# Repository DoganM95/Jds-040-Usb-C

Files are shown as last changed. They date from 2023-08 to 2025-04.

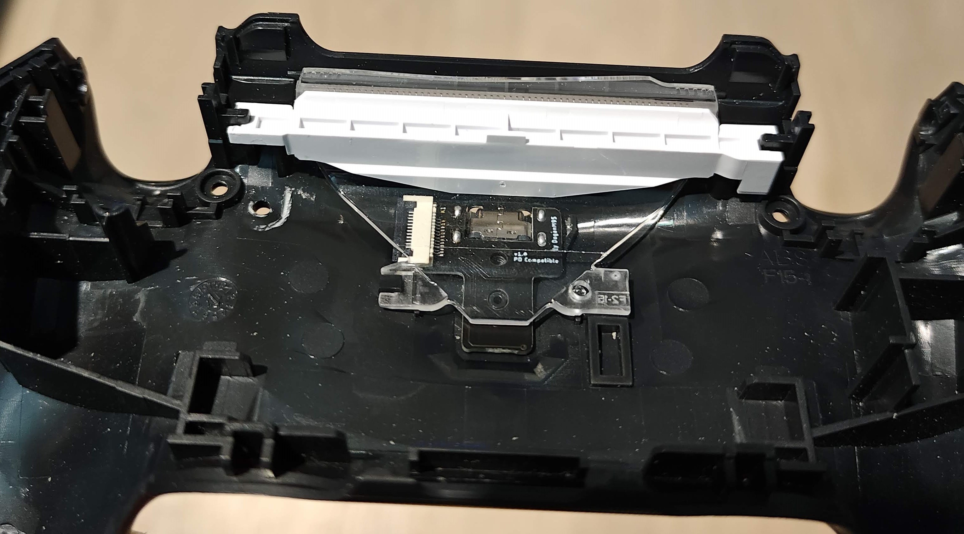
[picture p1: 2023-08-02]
assets/IMG_20230802_171910.jpg

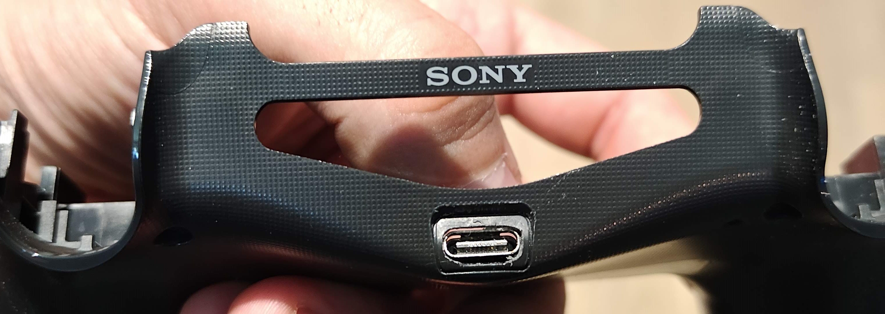
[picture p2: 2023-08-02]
assets/IMG_20230802_171401.jpg

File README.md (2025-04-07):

# DS4-UsbC-Mod

Custom pcb to replace Dualshock 4's micro b port with usb c (PD compatible). It was made to replace the jds-040 model but might be a compatible replacement for other models.

<table>
  <tr>
    <td>USB-C PCB Bottom View</td>
    <td>USB-C PCB Top View</td>
  </tr>
</table>

<table>
  <tr>
    <td>USB-C PCB Top View</td>
    <td>USB-C PCB Bottom View</td>
  </tr>
</table>

## FPC pinout

Starting with the pin that is closest to the charge port and ending with the pin that is closest to the led's:

1. GND
2. GND
3. D +
4. D -
5. GND
6. GND
7. Green LED (3V3_G)
8. Red LED VCC (2V2_G)
9. Blue LED VCC (3V_G)
10. LED VCC
11. USB 5V
12. USB 5V

## Key features
- Usb C port (with D+ and D-)
- Compatible with power delivery (communicates to get 5V)
- Compatible with any 5V usb port
- Uses easily accessible components (Aliexpress)
- Dual RGB led's

## Parts
- PCB: Get the latest gerber zip in releases and order it from Jlcpcb, with 1mm PCB thickness
- FPC connector (pins:12, pitch:0.5mm. Salvage it from an existing board -> ) https://a.aliexpress.com/_EjykXX1
- Led's (RGB, side view) https://a.aliexpress.com/_EHr7vQn
- Resistors (size:0603, res:5.1kOhm) https://a.aliexpress.com/_EIPYwrH
- USB C (female, pins:16, padding-bottom:0.8mm) https://a.aliexpress.com/_EJhQRSJ

## Tools (recommended next to the obvious)
- Hot plate
- Flux
- Solder wick
- Hot air gun

# Procedure
- Get the salvageable micro b module from aliexpress ready
- Use a hot air gun to desolder the usb micro b port
- Fire up the hot plate & put the pcb on it
- Steal the fpc connector from it
- Get the blank usb c pcb ready
- Solder the fpc connector to it (sides first in good position)
- Solder the usb c port's 4 shell pads in good position
- Solder usb c pins
- Solder solder smd resistors
- Solder smd led's
  - Put solder on the pcb pads
  - Put solder on the led's pads
  - Solder the middle 2 pins first
  - Solder the sides

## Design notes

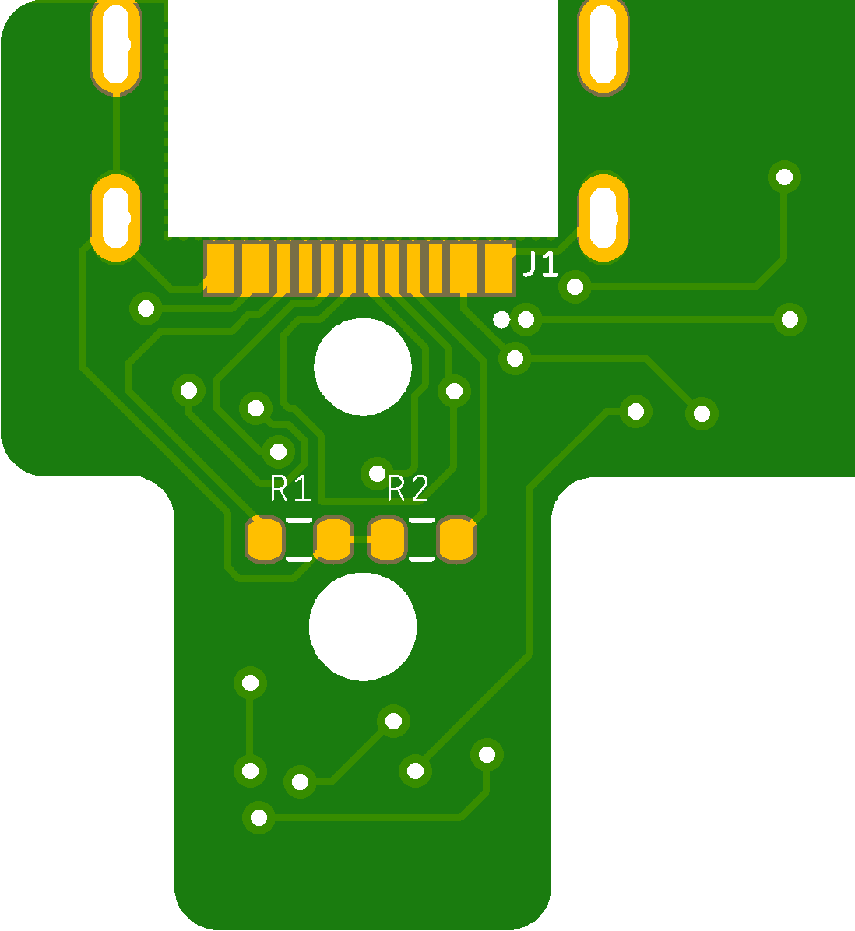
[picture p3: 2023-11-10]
assets/Jds-040-Usb-C_bottom.png

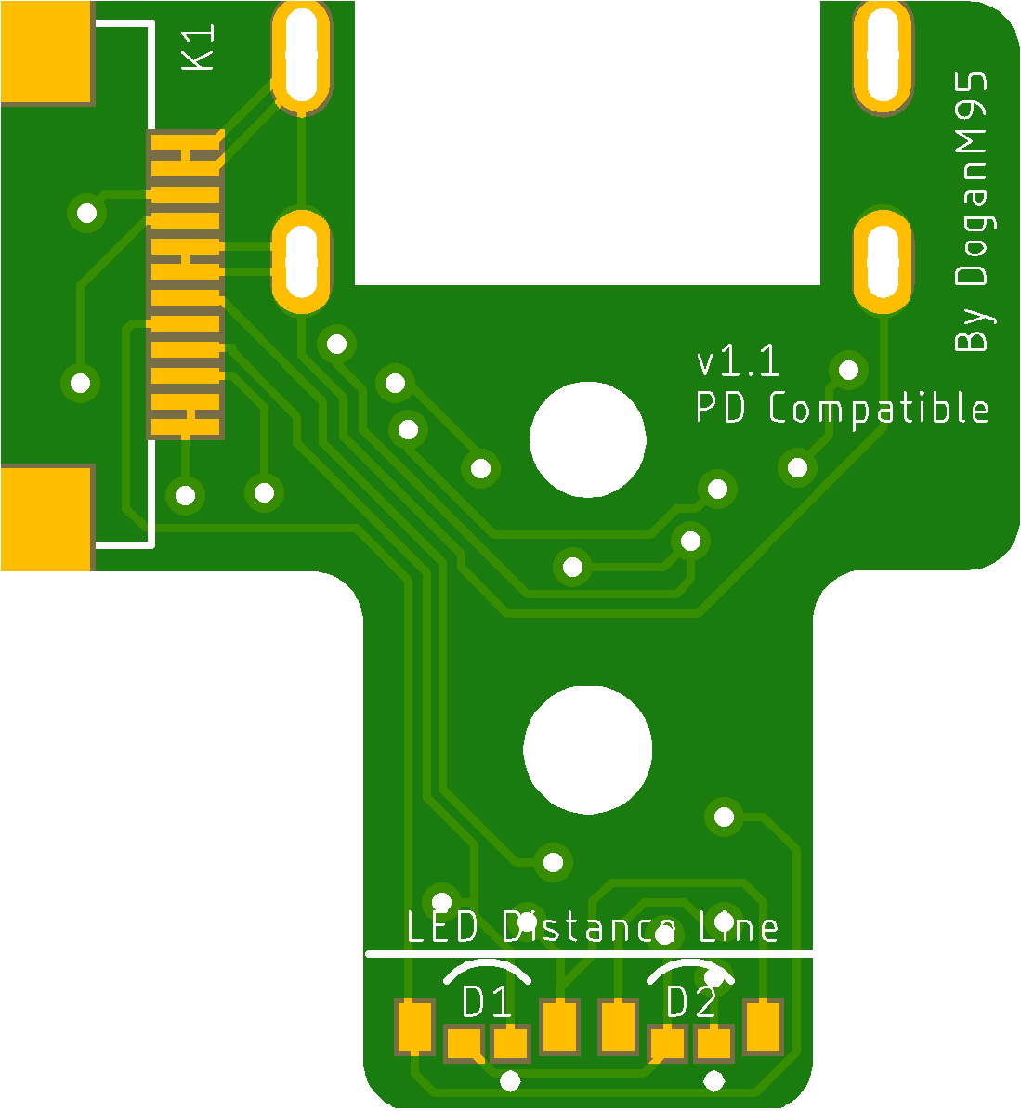
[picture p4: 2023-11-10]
assets/Jds-040-Usb-C_top.png

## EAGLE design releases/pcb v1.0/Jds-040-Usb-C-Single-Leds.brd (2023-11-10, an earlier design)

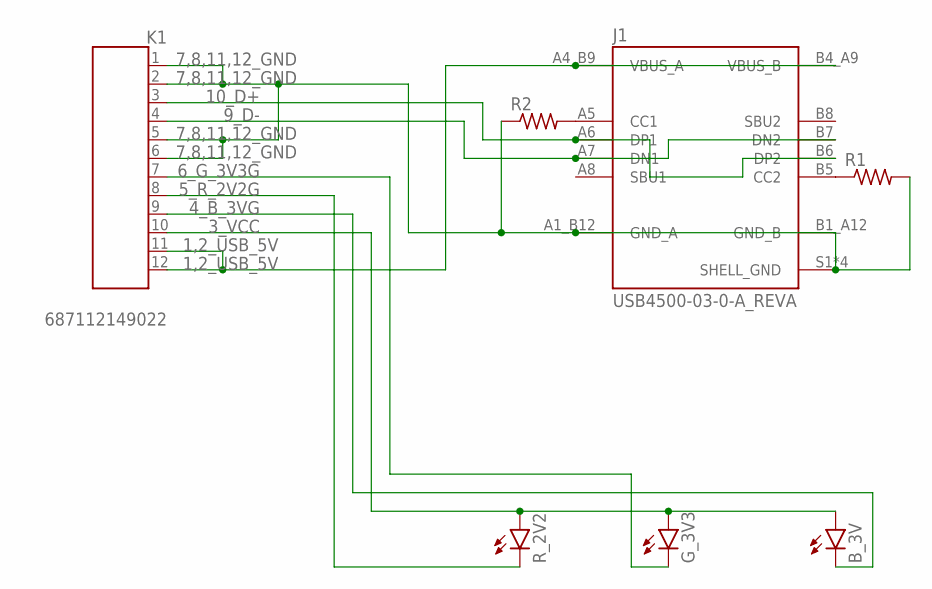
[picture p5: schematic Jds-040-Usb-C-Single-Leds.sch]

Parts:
B_3V: BEAGLEBONE_BLUE_LED0603; BEAGLEBONE_BLUE_BEAGLEBONE_BLUE_LED-0603
G_3V3: BEAGLEBONE_BLUE_LED0603; BEAGLEBONE_BLUE_BEAGLEBONE_BLUE_LED-0603
J1: USB4500-03-0-A_REVA; GCT_USB4500-03-0-A_REVA
K1: 687112149022
R1, R2: 5k1; RES_0603
R_2V2: BEAGLEBONE_BLUE_LED0603; BEAGLEBONE_BLUE_BEAGLEBONE_BLUE_LED-0603

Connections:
1,2_USB_5V: J1.A4_B9 (VBUS_A), J1.B4_A9 (VBUS_B), K1.11, K1.12
3_VCC: B_3V.A, G_3V3.A, K1.10, R_2V2.A
4_B_3VG: B_3V.C, K1.9
5_R_2V2G: K1.8, R_2V2.C
6_G_3V3G: G_3V3.C, K1.7
7,8,11,12_GND: J1.A1_B12 (GND_A), J1.B1_A12 (GND_B), J1.S1 (SHELL_GND), J1.S2 (SHELL_GND), J1.S3 (SHELL_GND), J1.S4 (SHELL_GND), K1.1, K1.2, K1.5, K1.6, R1.2, R2.1
9_D-: J1.A7 (DN1), J1.B7 (DN2), K1.4
10_D+: J1.A6 (DP1), J1.B6 (DP2), K1.3
unnamed: J1.B5 (CC2), R1.1
unnamed: J1.A5 (CC1), R2.2

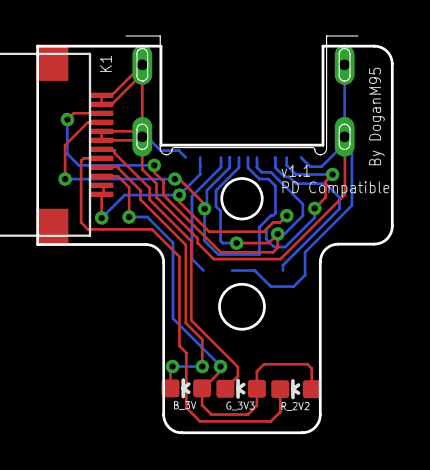
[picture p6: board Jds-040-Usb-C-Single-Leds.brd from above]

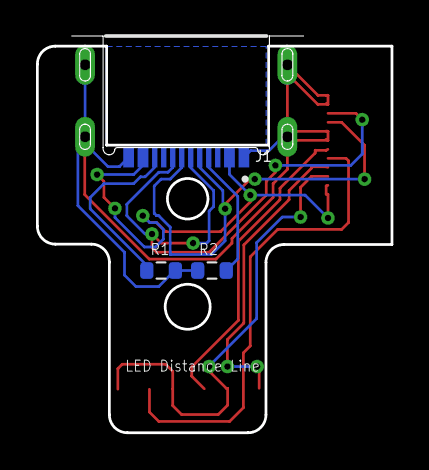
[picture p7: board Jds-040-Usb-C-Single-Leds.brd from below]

Board: 2 copper layers, 19.7 x 22.0 mm, 7 parts (3 on the bottom side), 10 nets.

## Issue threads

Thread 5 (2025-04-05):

Pcb tickness

crijopoga, 2025-04-05:
What is the tickness needed?. Great project!. Are also availables version for other mothels? (I could'nt find)

DoganM95, 2025-04-07:
Thanks, hickness is 1mm.
This is the only variant i built as i only have the jds-040 DS4, but theoretically it could work with jds-055 but you have to check the pinout first and need a flex calble that is long enough then i guess. will try adding the pinout to the readme, so you can verify

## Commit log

2023-08-02 add v1.1 gerber files
2023-08-20 add v1.1 pcb gerber
2023-08-30 add gbr files for v1.0
    [copper_bottom.gbr, copper_top.gbr, drill_1_16.xln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]
2023-08-30 add gbr files for v1.1
    [copper_bottom.gbr, copper_top.gbr, drill_1_16.xln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]
2023-11-10 restructure & open source
    [Jds-040-Usb-C-Single-Leds.brd, Jds-040-Usb-C-Single-Leds.sch, Jds-040-Usb-C.brd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]

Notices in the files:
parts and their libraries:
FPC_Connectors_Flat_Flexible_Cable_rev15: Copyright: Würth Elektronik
